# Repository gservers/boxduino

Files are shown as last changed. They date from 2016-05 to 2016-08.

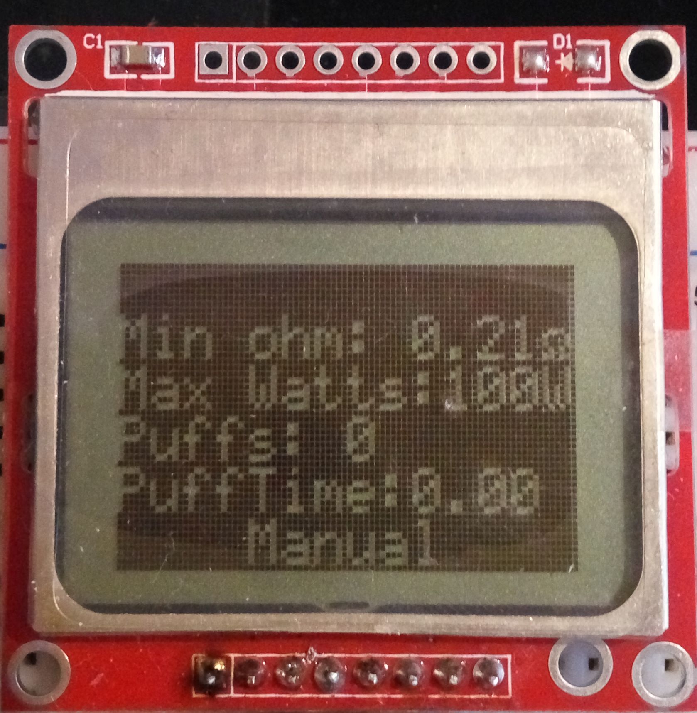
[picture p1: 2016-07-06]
Gallery/6.1.ManualStatistics+inverted.jpg

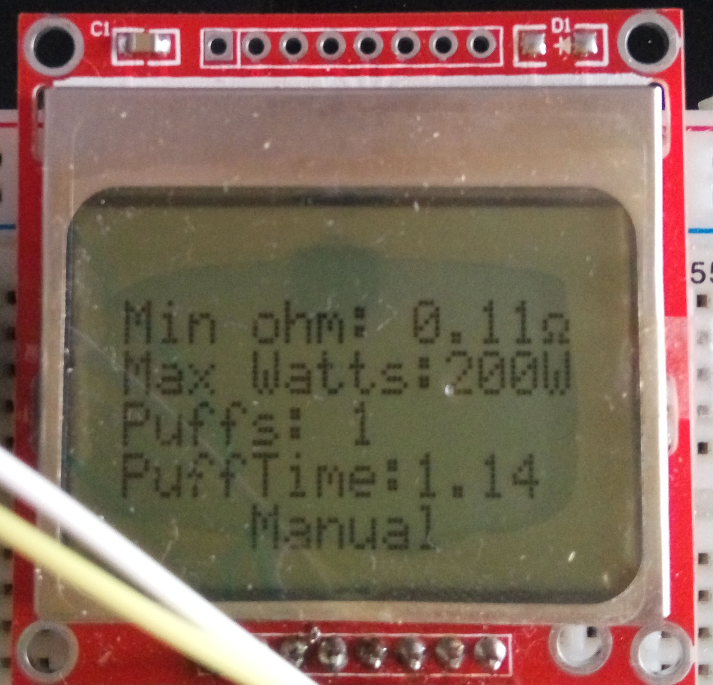
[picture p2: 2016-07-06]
Gallery/6.1.ManualStatistics.jpg

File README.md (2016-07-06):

# BOXduino - the first Arduino powered e-cigarette!  

Let me introduce You to one of the first almost open source Arduino BOX MOD - BOXduino!  
It took much work, and I'm still not finished! Time to solder this up, because breadboard tests are promising.

###Currently working:
  * Ohmmeter!  
  * Sleep / Power on - makes BOXduino more powersaving!  
  * Firing - It's self-explainatory! 
  * Read input voltage - Watch battery level!  
  * Battery indicator (pretty accurate) - with awesome bettery graphics!  
  * Nice display! - Pretty fine and readable layout  
  * Screen dimming! - afer 10 seconds without any action the screen will be dimmed.  
  * Standard control - see controls below  
  * Screen refreshing! - RMS voltage and resistance, the only thing that should be  
  * 1:1 Scheme - just solder it up! The only changes will be in code! (i hope)
  * Statistics submenu - check how low You can get, check puffs and mode

###Controls:  
  * Refresh everything: 1x click  
  * Fire: Hold the button  
  * Switch VV / Bypass: 3x click  
  * Night mode (inverting display): 4x click 
  * Power off: 5x click  
  * Power on: Hold the button (while off)  
  * Serial debug: 6x click  
  * Wakeup the screen: 1x click  
  * Change resistance (potentiometer on 0 and manual = true): 2x click
  * Check puffs, minimal resistance and max wattage: 2x click
  
###Ohmmeter
LM317 is taking over 125mA all the time, which makes me cry. Why would I waste my batteries for such thing?  
So i decided to use S8050 bipolar NPN transistor (up to 0.5A!) to supply power.
Now LM317 is powered just when I need to.

There are two modes available - manual and automatic.  
To change them edit bool called "manual".  

(false) Automatic is pretty easy to explain - ohmmeter circuit (and code) is calculating resistance almost all the time.    
(true) Manual - if You can't/don't want to add LM317 circuit, the resistance is set by yourself.  

You must know the resistance of the coil, but before I add TC it's just to show watts.  
Device will automatically ask for resistance, just turn potentiometer to desired value and press fire.  
To change, just press fire two times with potentiometer on 0.  

I didn't get any feedback, but if You find something hard to understand just pm me.  
##Check Issues for ToDo list and feel free to add new suggestions!

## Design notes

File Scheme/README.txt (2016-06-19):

1. Import PCD8544LCD.fzpz to Fritzing
2. Open BOXduino.fzz

My PCD8544 pinout:
Pin 1 - VCC
Pin 2 - GND
Pin 3 - SCE
Pin 4 - RST
Pin 5 - D/C
Pin 6 - DN(MOSI)
Pin 7 - SCLK
Pin 8 - Backlight
Please make sure Your pinout is the same or make needed fixes in Your circuit.
PCD8544.h will also need to be modified.

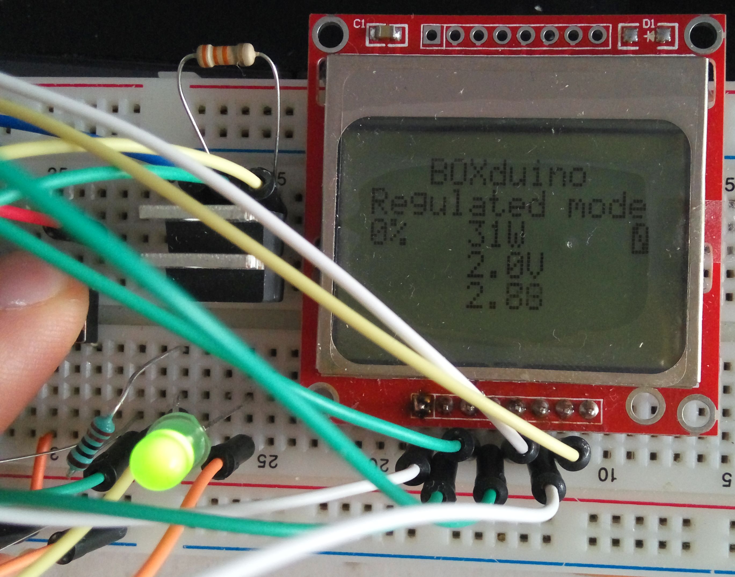
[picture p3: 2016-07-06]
Gallery/4.Firing.jpg

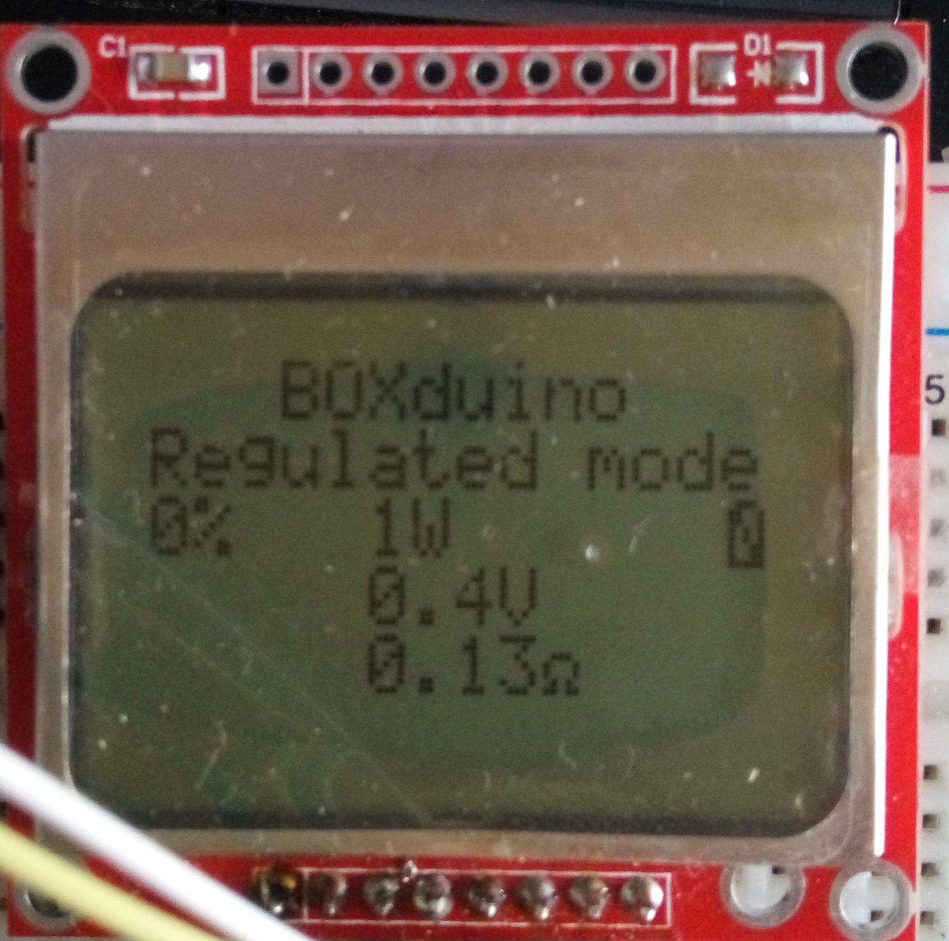
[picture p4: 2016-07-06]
Gallery/3.MainScreen.jpg

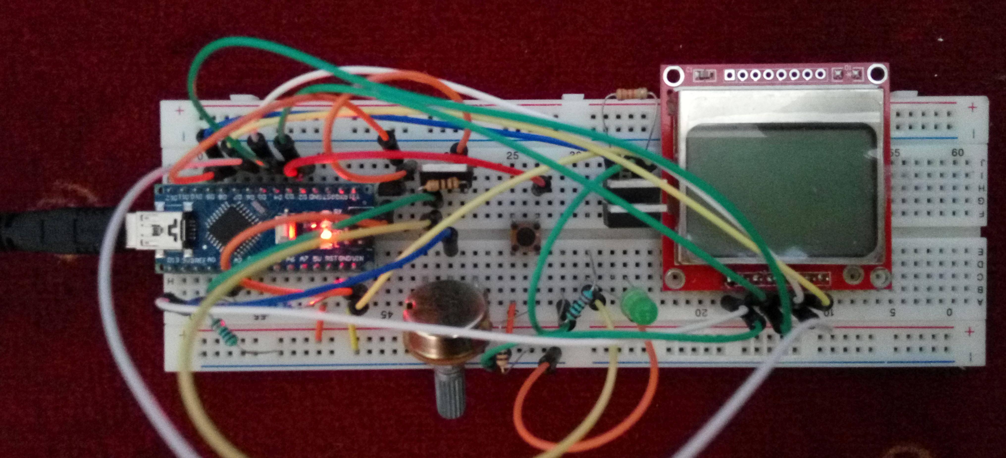
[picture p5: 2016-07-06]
Gallery/7.1.Breadboard.jpg

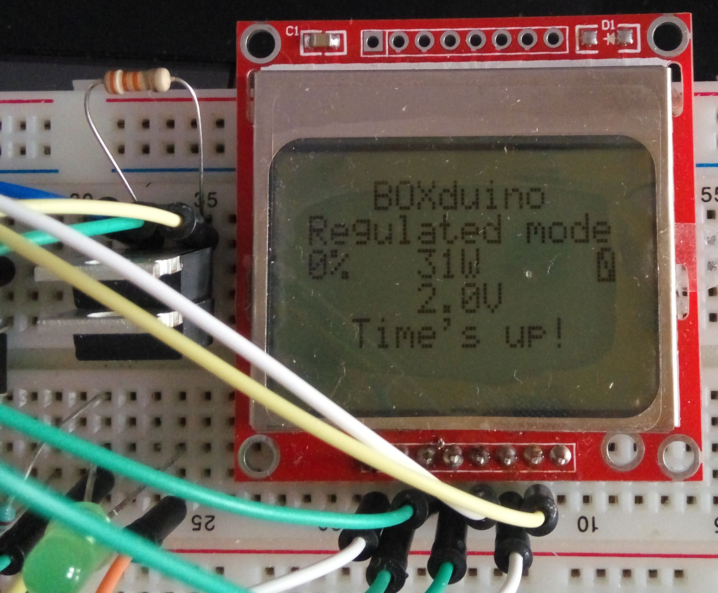
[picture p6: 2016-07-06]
Gallery/5.Timeout.jpg

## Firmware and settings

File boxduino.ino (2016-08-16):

/*  Arduino controlled box mod by Marek Ledworowski.
    I'm not responsible for dead MCU's, burnt PC's,
    smoked cigarettes or electrocutions.
    I'm not responsible for this sketch, even if it
    poops on your lawn - You let him do it.

    Please don't sell it as Yours, but feel free to use
    it WITHOUT financial benefits.
    Any questions? Contact me at fotelpl@gmail.com

    To do:
      - lock for too low/high resistance
      - lock for too high power
*/

#include "libraries/PCD8544/PCD8544.h" //LCD Library
#include "libraries/ClickButton/ClickButton.h" //Fire button driver
#include <avr/sleep.h> //Sleeping lib
#include <avr/power.h> //^up
static PCD8544 lcd;
bool manual = true; //true for LM317 circiut, false for manual setting
bool on = true; //Check if powered
bool inv = false; //Screen inverted
bool lock = false; //Autofire
const int baud = 9600; //Serial baudrate
const int maxwatt = 100; //Max watts

ClickButton fire(2, HIGH); //Define fire button as object
const int pfet = 9; //Trigger (+) channel of P-FET
const int ohmmetpower = 8; //Ohmmeter power supply
const int pot = A0; //Potentiometer
const int volt = A1; // Vin voltmeter
const int ohmmet = A2; //Ohmmeter output

const int probes = 15; //How many resistance samples will be taken
const float r1 = 1000000.0; //R1 of Vin voltmeter
const float r2 = 100000.0; //R2 Vin voltmeter
const float vin = 8.4; //Max. supply voltage
const float vbord = 6; //Max. discharge voltage
const float ohmcal = 0.08; //Resistance of connections, just put copper wire between pins.
//Check the readings and change value if needed

int mode = 0; //0 - VV/VW, 1 - BYPASS
int cnt = 0; //How many times button was pressed
long int tempnow; //First click
long int tempend; //Last click
long int lastpress = 0; //Last button press
unsigned int puffs = 0; //Total puffs
float pufftime = 0; //Total puff time

float state = 0; //% of potentiometer scale
float rms = 0;  //RMS voltage
float duty = 0; //duty cycle (0-255)
float vbat = 0; //Vin voltage
float cbat = 0; //Baterry %
float res = 0; //Resistance
float minres = 0; //Minimal resistance
int watts = 0; //Watts

const int timeout = 10; //Fire limit
const int dim = 10; //Disable display limit

const unsigned char full[] = {
  0xFE, 0xFF, 0xFF, 0xFF, 0xFE
};
const unsigned char hi[] = {
  0xFE, 0xFD, 0xFD, 0xFD, 0xFE
};
const unsigned char med[] = {
  0xFE, 0xF1, 0xF1, 0xF1, 0xFE
};
const unsigned char low[] = {
  0xFE, 0xC1, 0xC1, 0xC1, 0xFE
};
const unsigned char empty[] = {
  0xFE, 0x87, 0x99, 0xE1, 0xFE
};
const unsigned char ohm[] = {
  0x58, 0x64, 0x04, 0x64, 0x58
};
const unsigned char splashscreen[] = {
  0x00, 0x00, 0x00, 0xFE, 0x0C, 0x30, 0x60, 0x30, 0x0C, 0xFE, 0x00, 0x80, 0x40, 0x40, 0x40, 0xC0, 0x00, 0x00, 0xC0, 0x80, 0x40, 0x40, 0x00, 0x80, 0x40, 0x40, 0x40, 0x80, 0x00, 0x80, 0x40, 0x40, 0x40, 0x00, 0xFE, 0x00, 0x00, 0x00, 0x00, 0x00, 0x08, 0x04, 0x02, 0x80, 0x40, 0x20, 0x40, 0x80, 0x00, 0x00, 0x00, 0x00, 0x00, 0x00, 0x00, 0x00, 0x00, 0x00, 0x00, 0x00, 0x00, 0x00, 0x00, 0xC0, 0x40, 0x78, 0x7C, 0x78, 0x40, 0xC0, 0x00, 0x00, 0x00, 0x00, 0x00, 0x00, 0x00, 0x00, 0x00, 0x00, 0x00, 0x00, 0x00, 0x00,
  0x00, 0x00, 0x00, 0x07, 0x00, 0x00, 0x00, 0x00, 0x00, 0x07, 0x00, 0x03, 0xF4, 0x14, 0x14, 0x13, 0xE4, 0x00, 0x07, 0x00, 0x00, 0x00, 0x00, 0x03, 0x05, 0x05, 0x05, 0x00, 0x00, 0x03, 0x04, 0x04, 0x04, 0x00, 0x03, 0xF4, 0x04, 0x04, 0x02, 0x00, 0x00, 0x00, 0x00, 0x04, 0x84, 0x04, 0x02, 0x01, 0x00, 0x00, 0x00, 0x00, 0x00, 0x00, 0x00, 0x00, 0x00, 0x00, 0x00, 0x00, 0x00, 0x00, 0x03, 0xFF, 0x00, 0x0F, 0x05, 0x0F, 0x00, 0xFF, 0x00, 0x00, 0x00, 0x00, 0x00, 0x00, 0x00, 0x00, 0x00, 0x00, 0x00, 0x00, 0x00, 0x00,
  0x00, 0x00, 0x00, 0x00, 0x00, 0x00, 0x00, 0x00, 0x00, 0x00, 0x00, 0x00, 0x3F, 0x21, 0x21, 0x21, 0x22, 0x1C, 0x00, 0x1C, 0x22, 0x22, 0x22, 0x1C, 0x00, 0x22, 0x14, 0x08, 0x14, 0x22, 0x00, 0x1C, 0x22, 0x22, 0x22, 0x3F, 0x00, 0x1E, 0x20, 0x20, 0x20, 0x1E, 0x20, 0x00, 0x3E, 0x00, 0x3E, 0x04, 0x02, 0x02, 0x3C, 0x00, 0x1C, 0x22, 0x22, 0x22, 0x1C, 0x00, 0x00, 0x00, 0x00, 0x00, 0x00, 0x03, 0x02, 0x02, 0x02, 0x02, 0x02, 0x03, 0x00, 0x00, 0x00, 0x00, 0x00, 0x00, 0x00, 0x00, 0x00, 0x00, 0x00, 0x00, 0x00, 0x00,
  0x00, 0x00, 0x00, 0x00, 0x00, 0x00, 0x00, 0x00, 0x00, 0x00, 0x00, 0x00, 0x00, 0x00, 0x00, 0x00, 0x00, 0x00, 0x00, 0x00, 0x00, 0x00, 0x00, 0x00, 0x00, 0x00, 0x00, 0x00, 0x00, 0x00, 0x00, 0x00, 0x00, 0x00, 0x00, 0x00, 0x00, 0x00, 0x00, 0x00, 0x00, 0x00, 0x00, 0x00, 0x00, 0x00, 0x00, 0x00, 0x00, 0x00, 0x00, 0x00, 0x00, 0x00, 0x00, 0x00, 0x00, 0x00, 0x00, 0x00, 0x00, 0x00, 0x00, 0x00, 0x00, 0x00, 0x00, 0x00, 0x00, 0x00, 0x00, 0x00, 0x00, 0x00, 0x00, 0x00, 0x00, 0x00, 0x00, 0x00, 0x00, 0x00, 0x00, 0x00,
  0x00, 0x00, 0x00, 0x00, 0x00, 0x00, 0x00, 0x00, 0x00, 0x00, 0x00, 0x00, 0x00, 0x00, 0x00, 0x00, 0x00, 0x00, 0x00, 0x00, 0x00, 0x00, 0x00, 0x00, 0x00, 0x00, 0x00, 0x00, 0x00, 0x00, 0x00, 0x00, 0x00, 0x00, 0x00, 0x00, 0x00, 0x00, 0x00, 0x00, 0x00, 0x00, 0x00, 0x00, 0x00, 0x00, 0x00, 0x00, 0x00, 0x00, 0x00, 0x00, 0x00, 0x00, 0x00, 0x00, 0x00, 0x00, 0x00, 0x00, 0x00, 0x00, 0x00, 0x00, 0x00, 0x00, 0x00, 0x00, 0x00, 0x00, 0x00, 0x00, 0x00, 0x00, 0x00, 0x00, 0x00, 0x00, 0x00, 0x00, 0x00, 0x00, 0x00, 0x00,
  0x00, 0x00, 0x00, 0x00, 0x00, 0x00, 0x00, 0x00, 0x00, 0x00, 0x00, 0x00, 0x00, 0x00, 0x00, 0x00, 0x00, 0x00, 0x00, 0x00, 0x00, 0x00, 0x00, 0x00, 0x00, 0x00, 0x00, 0x00, 0x00, 0x00, 0x00, 0x00, 0x00, 0x00, 0x00, 0x00, 0x00, 0x00, 0x00, 0x00, 0x00, 0x00, 0x00, 0x00, 0x00, 0x00, 0x00, 0x00, 0x00, 0x00, 0x00, 0x00, 0x00, 0x00, 0x00, 0x00, 0x00, 0x00, 0x00, 0x00, 0x00, 0x00, 0x00, 0x00, 0x00, 0x00, 0x00, 0x00, 0x00, 0x00, 0x00, 0x00, 0x00, 0x00, 0x00, 0x00, 0x00, 0x00, 0x00, 0x00, 0x00, 0x00, 0x00, 0x00
};
void setup() {
  lcd.begin();
  lcd.setContrast(65); //We want to see something, right?
  lcd.drawBitmap(splashscreen, 84, 48);
  setPwmFrequency(9, 1); //31372.55Hz, 256 cycle length (0-255)
  pinMode(pot, INPUT); //Potentiometer
  pinMode(volt, INPUT); //Voltmeter
  pinMode(2, INPUT); //Button
  pinMode(pfet, OUTPUT); //P-FET transistor out
  pinMode(ohmmetpower, OUTPUT); //Ohmmeter power supply
  pinMode(ohmmet, INPUT); //Ohmmeter
  prepchar(); //Send custom chars to display's RAM
  fire.debounceTime = 10; //Single click
  fire.multiclickTime = 400; //Time for many clicks
  fire.longClickTime = 200; //Long click timer
  on = true; //Set this flag to enable screen and stuff
  digitalWrite(pfet, HIGH); //Make sure it won't fire without us
  digitalWrite(ohmmetpower, LOW); //Disable ohmmeter
  vbat = gainvbat(volt, r1, r2); //Performing initial calculations
  minres = vbat * vbat / maxwatt;
  switch (mode) {
    case 0: //VV/VW
      duty = gainduty(pot); rms = gainrms(vbat, duty);
      watts = round(rms * rms / res); break;
    case 1: //Bypass
      duty = 255; rms = vbat; break;
  } //As far, we're finished
  delay(1500);
  lcd.clear();
  if (manual == false)
    res = gainres(ohmmetpower, ohmmet, probes); //LM317 is present so it checks resistance
  else res = setohm(pot); //No LM317 = no automatic updates
  lcd.setCursor(0, 0);
  printstate(vbat, duty, rms, mode, res);
  lastpress = millis();
}

void loop() {
  fire.Update();
  vbat = gainvbat(volt, r1, r2);
  switch (mode) {
    case 0:
      duty = gainduty(pot); rms = gainrms(vbat, duty);
      watts = round(rms * rms / res); break;
    case 1:
      duty = 255; rms = vbat;
      watts = round(rms * rms / res); break;
  }

  lcd.setCursor(30, 2);
  lcd.print(watts);
  lcd.print("W  ");
  lcd.setCursor(30, 3);
  lcd.print(rms, 1);
  lcd.print("V");
  lcd.setCursor(30, 4);
  if (res > 9.99) res = 9.99;
  if (res < 0.03) res = 0.00;
  lcd.print(res, 2);
  lcd.write(0);

  duty = abs(duty - 255); //P-FET transistor reacts to low state soooo...
  //The value must be inverted
  fire.Update();
  cnt = fire.clicks;
  if (cnt != 0) lastpress = millis();
  switch (cnt) {
    case -1:
      if (digitalRead(2) == 1 && lock == false && res > minres) {
        printstate(vbat, duty, rms, mode, res);
        go(pfet, duty, 2);
        printstate(vbat, duty, rms, mode, res);
      }
      if (digitalRead(2) == 1 && lock == false && res < minres) {
        lcd.setCursor(0, 3);
        lcd.print(" Too low ohm!");
        while (digitalRead(2) == HIGH) {}
        lcd.clearLine();
      }
      break;
    case 1:
      if (lock == true) {
        lcd.begin();
        lcd.setContrast(65);
      }
      else if (manual == false) res = gainres(ohmmetpower, ohmmet, probes);
      lock = false;
      prepchar();
      printstate(vbat, duty, rms, mode, res); break;
    case 2:
      lcd.clear();
      if (/*manual == true && */analogRead(pot) <= 5) res = setohm(pot);
      else {
        lcd.setCursor(0, 0);
        lcd.print("Min ohm: ");
        lcd.print(minres);
        lcd.write(0);
        lcd.setCursor(0, 1);
        lcd.print("Max Watts:");
        lcd.print(maxwatt);
        lcd.print("W");
        lcd.setCursor(0, 2);
        lcd.print("Puffs: ");
        lcd.print(puffs);
        lcd.setCursor(0, 3);
        lcd.print("PuffTime:");
        lcd.print(pufftime, 2);
        lcd.setCursor(0, 5);
        if (manual == true)lcd.print("    Manual");
        else lcd.print("  Automatic");
        delay(2000);
      }
      lcd.clear();
      printstate(vbat, duty, rms, mode, res); break;
    case 3:
      if (mode == 1) {
        mode = 0;
        duty = gainduty(pot);
        rms = gainrms(vbat, duty);
        watts = round(rms * rms / res);
      } else {
        mode = 1;
        duty = 255;
        rms = vbat;
      }
      printstate(vbat, duty, rms, mode, res); break;
    case 4:
      if (inv == 1) inv = 0; else inv = 1;
      lcd.setInverse(inv); break;
    case 5:
      on = false; power();
      printstate(vbat, duty, rms, mode, res); break;
    case 6:
      serv(baud, vbat, duty, rms, mode, puffs, pufftime, res); break;
  }
  if (cnt != 0) lastpress = millis();
  if ((millis() - lastpress) >= (dim * 1000) && cnt == 0 && lock == false) {
    lcd.stop();
    lock = true;
  }
}
//MOSFET port, duty cycle, fire button port
void go(int pftmp, float dutmp, int fitmp) {
  float czas = millis();
  float licz = 0;
  lcd.setCursor(0, 4);
  lcd.clearLine();
  analogWrite(pfet, dutmp);
  while (digitalRead(fitmp) != 0 && licz <= timeout) { //It's not rocket science
    licz = (millis() - czas) / 1000;
    lcd.setCursor(30, 4);
    lcd.print(licz, 2);
  }
  digitalWrite(pfet, HIGH);
  delay(5);
  if (licz >= timeout) {
    lcd.setCursor(33, 4);
    delay(45);
    lcd.print("10.00");
    lcd.clearLine();
    lcd.print("  Time's up!  ");
    while (digitalRead(fitmp) == 1) {}
    delay(2500);
    lcd.clearLine();
    licz = timeout;
  }
  pufftime += licz;
  lcd.setCursor(0, 4);
  lcd.clearLine();
  puffs = puffs + 1;
}
//Potentiometer port
int gainduty(float potmp) {
  float dutmp = analogRead(potmp);
  Serial.print(duty);
  Serial.print(" | ");
  dutmp = map(dutmp, 0, 1023, 0, 255);
  Serial.println(duty);
  return (dutmp);
}
//Vin voltmeter port, R1, R2
float gainvbat(int batmp, float rtmp1, float rtmp2) {
  float vbatmp = ((analogRead(batmp) * 5.0) / 1024.0) / (rtmp2 / (rtmp1 + rtmp2));
  return (vbatmp);
}
//Vin voltage, duty cycle
float gainrms(float vbatmp, float dutmp) {
  float statmp = (dutmp * 100) / 255; //Stan w %
  float rmstmp = vbatmp * sqrt(statmp / 100); //RMS
  return (rmstmp);
}
float setohm(int potmp) { //If you know resistance of coil
  float tempohm;
  lcd.setCursor(0, 0);
  lcd.print("Set Resistance");
  lcd.setCursor(0, 2);
  lcd.print("Min ohm: ");
  lcd.print(minres);
  lcd.write(0);
  lcd.setCursor(0, 3);
  lcd.print("Max Watts:");
  lcd.print(maxwatt);
  lcd.print("W");
  lcd.setCursor(0, 4);
  lcd.print("Puffs: ");
  lcd.println(puffs);
  lcd.setCursor(0, 5);
  lcd.print("PuffTime:");
  lcd.println(pufftime, 1);
  while (digitalRead(2) != true) {
    lcd.setCursor(0, 0);
    lcd.print("Set Resistance");
    tempohm = analogRead(potmp);
    tempohm /= 1023.0; //9.99 ohm max
    tempohm *= 999;
    tempohm = ceil(tempohm);
    tempohm /= 100;
    lcd.setCursor(30, 1);
    lcd.print(tempohm);
    lcd.write(0);
  }
  lcd.clear();
  return (tempohm);
}
//Ohmmeter power supply pin, ohmmeter reading pin, how many probes
//Remember to DISABLE P-FET transistor and/or N-FET!
float gainres(int ohmsuptmp, int ohmmetmp, int probetmp) {
  float tempres = 0;
  float tp = 0;
  digitalWrite(ohmsuptmp, HIGH);
  delayMicroseconds(10);
  for (int a = 0; a < probes; a++) {
    tp = analogRead(ohmmetmp);
    tp = tp * 5 / 1023;
    tp = tp / 0.125;
    tempres += tp;
  }
  digitalWrite(ohmsuptmp, LOW);
  tempres /= probetmp;
  tempres -= ohmcal;
  return (tempres);
}
//Shutdown
void power() {
  digitalWrite(pfet, HIGH);
  do {
    attachInterrupt(2, poweron, HIGH);
    lcd.stop();
    set_sleep_mode(SLEEP_MODE_IDLE);
    sleep_enable();
    sleep_mode();
    sleep_disable();
    long int teemp = millis();
    while (digitalRead(2) == HIGH) {
      if ((millis() - teemp) >= 2500) on = true;
    }
    detachInterrupt(2);
    if (on == true) lcd.setPower(true); //Do something here to show it's working again
  } while (on == false);
}
void poweron() {
  detachInterrupt(2);
}
void prepchar() {
  lcd.createChar(0, ohm);
  lcd.createChar(1, full);
  lcd.createChar(2, hi);
  lcd.createChar(3, med);
  lcd.createChar(4, low);
  lcd.createChar(5, empty);
}
void serv(int tmpbaud, float vbatmp, float dutmp, float rmstmp, int modtmp, int pufftmp, float pufftmp2, float restmp) {
  Serial.begin(tmpbaud);
  Serial.println("BOXduino service mode");
  Serial.print("Supply voltage: ");
  Serial.print(vbatmp, 1);
  Serial.print("V\n");
  Serial.print("Mode: ");
  if (mode == 0) Serial.print("Regulated\n");
  if (mode == 1) Serial.print("Bypass\n");
  Serial.print("RMS voltage: ");
  Serial.print(rmstmp, 1);
  Serial.print("V\n");
  Serial.print("Digital duty cycle: ");
  Serial.print(dutmp, 0);
  Serial.print("/255\n");
  Serial.print("Puffs: ");
  Serial.println(pufftmp);
  Serial.print("Puff time: ");
  Serial.print(pufftmp2, 2);
  Serial.println("s");
  Serial.print("Resistance: ");
  Serial.print(restmp);
  Serial.println("ohm");
  Serial.println("-=-=-=-=-=-=-=-=-=-=-=-=-=-=-");
  Serial.end();
}
void printstate(float vbatmp, float dutmp, float rmstmp, int modtmp, float restmp) {
  cbat = ((vbatmp - vbord) * 100);
  if (cbat < 0) cbat = 0;
  lcd.setCursor(0, 0);
  lcd.print("   BOXduino");
  lcd.setCursor(0, 1);
  if (modtmp == 0) lcd.print("Regulated mode");
  if (modtmp == 1) lcd.print(" Bypass mode! ");
  lcd.setCursor(0, 2);
  lcd.print(cbat, 0);
  lcd.print("% ");
  lcd.setCursor(30, 2);
  int watts = round(rms * rms / res);
  lcd.print(watts);
  lcd.print("W   ");
  lcd.setCursor(79, 2);
  if (cbat <= 100 && cbat >= 95) lcd.write(1);
  if (cbat < 95 && cbat >= 70) lcd.write(2);
  if (cbat < 70 && cbat >= 40) lcd.write(3);
  if (cbat < 40 && cbat >= 15) lcd.write(4);
  if (cbat < 15) lcd.write(5);
  lcd.setCursor(30, 3);
  lcd.print(rmstmp, 1);
  lcd.print("V");
  lcd.setCursor(30, 4);
  if (restmp > 9.99) restmp = 9.99;
  if (restmp < 0.03) restmp = 0.00;
  lcd.print(restmp, 2);
  lcd.write(0);
}
void setPwmFrequency(int pin, int divisor) {
  byte mode;
  if (pin == 5 || pin == 6 || pin == 9 || pin == 10) {
    switch (divisor) {
      case 1: mode = 0x01; break;
      case 8: mode = 0x02; break;
      case 64: mode = 0x03; break;
      case 256: mode = 0x04; break;
      case 1024: mode = 0x05; break;
      default: return;
    }
    if (pin == 5 || pin == 6) {
      TCCR0B = TCCR0B & 0b11111000 | mode;
    } else {
      TCCR1B = TCCR1B & 0b11111000 | mode;
    }
  } else if (pin == 3 || pin == 11) {
    switch (divisor) {
      case 1: mode = 0x01; break;
      case 8: mode = 0x02; break;
      case 32: mode = 0x03; break;
      case 64: mode = 0x04; break;
      case 128: mode = 0x05; break;
      case 256: mode = 0x06; break;
      case 1024: mode = 0x7; break;
      default: return;
    }
    TCCR2B = TCCR2B & 0b11111000 | mode;
  }
}

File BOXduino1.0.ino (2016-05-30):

/*  Arduino controlled box mod by Marek Ledworowski
    Before committing changes please contact me first
    at fotelpl@gmail.com .
    I'm not responsible for dead MCU's, burnt lungs
    and all stuff that may be dangerous or sad.
    Version 1.0
*/
    
#include <avr/sleep.h>
#include <avr/power.h>
#include <LiquidCrystal.h>
LiquidCrystal lcd(7, 8, 9, 10, 11, 12);
bool on = true; //Stan wlaczenia
const int fire = 2; //Przycisk
const int mosfet = 6; //Wyjscie (PWM)
const int pot = A0; //Potencjometr
const int volt = A1; //Woltomierz Vin
const int bcg = A2; //Podswietlenie ekranu

int mode = 0; //0 - VV/VW, 1 - BYPASS
int bouncedelay = 100;
int holddelay = 500;

long int tempnow; //Poczatek klikania
long int tempend; //Koniec klikania

const float r1 = 1000000.0; //R1 woltomierza Vin
const float r2 = 100000.0; //R2 woltomierza Vin

float state = 0; //Wychylenie w %
float rms = 0;  //Napięcie RMS
float duty = 0; //Dlugosc cyklu 0-255
float vbat = 0; //Napiecie zasilania
float vin = 8.4; //Napiecie referencyjne zasilania
float vbord = 6; //Granic rozladowania
float cbat = 0; //% naladowania baterii
float ohm = 0; //omomierz
float light = 256.0; //Jasnosc podswietlenia
byte full[8] = {
  B00000,
  B01110,
  B11111,
  B11111,
  B11111,
  B11111,
  B11111,
  B00000,
};
byte hi[8] = {
  B00000,
  B01110,
  B10001,
  B11111,
  B11111,
  B11111,
  B11111,
  B00000,
};
byte med[8] = {
  B00000,
  B01110,
  B10001,
  B10001,
  B11111,
  B11111,
  B11111,
  B00000,
};
byte low[8] = {
  B00000,
  B01110,
  B10001,
  B10001,
  B10001,
  B11111,
  B11111,
  B00000,
};
byte empty[8] = {
  B00000,
  B01110,
  B11001,
  B10101,
  B10101,
  B10011,
  B11111,
  B00000,
};
void setup() {
  pinMode(pot, INPUT);
  pinMode(volt, INPUT);
  pinMode(bcg, OUTPUT);
  pinMode(fire, INPUT);
  pinMode(mosfet, OUTPUT);
  lcd.begin(16, 2);
  lcd.createChar(0, full);
  lcd.createChar(1, hi);
  lcd.createChar(2, med);
  lcd.createChar(3, low);
  lcd.createChar(4, empty);
  analogWrite(bcg, light);
  vbat = gainvbat(volt, r1, r2);
  duty = gainduty(pot);
  rms = gainrms(vbat, duty);
  scheme(mode);
  updatebat(vbat);
}
void loop() {
  vbat = gainvbat(volt, r1, r2);
  duty = gainduty(pot);
  rms = gainrms(vbat, duty);
  scheme(mode);
  updatedata(rms, mode);
  if (millis() % 2000 == 0) updatebat(vbat);

  if (rms < 0.1 && digitalRead(fire) == HIGH ) {
    tempnow = millis();
    while (digitalRead(fire) == HIGH) {}
    tempend = millis();
    if ((tempend - tempnow) >= holddelay) {
      on = false;
      power();
    } else if ((tempend - tempnow) < bouncedelay) {
      if (mode == 1) mode = 0;
      else mode = 1;
      lcd.clear();
    }
  } else if (digitalRead(fire) == HIGH && rms >= 0.1) {
    tempnow = millis();
    while (millis() - tempnow < bouncedelay && digitalRead(fire) == HIGH) {}
    if (mode == 0 && digitalRead(fire) == HIGH) watt(mosfet, duty, fire);
    if (mode == 1 && digitalRead(fire) == HIGH) bypass(mosfet, fire);
    updatebat(vbat);
  }
  delay(10);
}

void scheme(int motmp) {
  lcd.setCursor(0, 0);
  if (mode == 0)
    lcd.print(" VAPE AT: ");
  if (mode == 1)
    lcd.print("BYPASS AT: ");
}

void updatebat(float tmpvbat) {
  float cbat = ((tmpvbat - vbord) * 100) / vin;
  if (cbat < 0) cbat = 0;
  if (cbat == 100) lcd.setCursor(10, 1);
  if (cbat < 100 && cbat >= 10) lcd.setCursor(11, 1);
  if (cbat < 10) lcd.setCursor(12, 1);
  lcd.print(cbat, 0);
  lcd.print("% ");
  if (cbat <= 100 && cbat >= 95) lcd.write(byte(0));
  if (cbat < 95 && cbat >= 70) lcd.write(byte(1));
  if (cbat < 70 && cbat >= 40) lcd.write(byte(2));
  if (cbat < 40 && cbat >= 15) lcd.write(byte(3));
  if (cbat < 15) lcd.write(byte(4));
  lcd.setCursor(0, 0);
}

void updatedata(float rmstmp, float motmp) {
  if (motmp == 0) {
    lcd.setCursor(10, 0);
    lcd.print(rms, 1);
    lcd.print("V");
  }
}

void watt(int mostmp, float dutmp, int fitmp) { //mosfet, duty, fire
  float czas = millis();
  float licz = 0;
  analogWrite(mostmp, dutmp);
  while (digitalRead(fitmp) != 0 && licz < 10)
    licz = (millis() - czas) / 1000;
  analogWrite(mostmp, 0.0);
  if (licz >= 10) {
    while (digitalRead(fitmp) == 1) {}
    delay(2500);
  }
}

void bypass(int mostmp, int fitmp) { //mosfet, fire
  float czas = millis();
  float licz = 0;
  analogWrite(mostmp, 255);
  while (digitalRead(fitmp) != 0 && licz < 10)
    licz = (millis() - czas) / 1000;
  analogWrite(mostmp, 0.0);
  if (licz >= 10) {
    while (digitalRead(fitmp) == 1) {};
    delay(2500);
  }
}

float gainvbat(int batmp, float rtmp1, float rtmp2) {
  float value = analogRead(batmp);
  float vout = (value * 5.0) / 1024.0;
  float vbatmp = vout / (rtmp2 / (rtmp1 + rtmp2));
  return (vbatmp);
}

int gainduty(float potmp) {
  float dutmp = analogRead(potmp);
  dutmp /= 4;
  dutmp = round(dutmp);
  return (dutmp);
}

float gainrms(float vbatmp, float dutmp) {
  float statmp = (dutmp * 100) / 255; //Stan w %
  float rmstmp = vbatmp * sqrt(statmp / 100); //RMS
  return (rmstmp);
}

void power() {
  attachInterrupt(fire, poweron, HIGH);
  lcd.clear();
  analogWrite(bcg, 0.0);
  lcd.noDisplay();
  set_sleep_mode(SLEEP_MODE_IDLE);
  sleep_enable();
  sleep_mode();
  while (on == false && digitalRead(fire) == LOW) {}
  if (on == false) poweron();
  sleep_disable();
  lcd.display();
  analogWrite(bcg, light);
}

void poweron() {
  detachInterrupt(fire);
  long int teemp = millis();
  while (digitalRead(fire) == HIGH) {}
  if ((millis() - teemp) >= 2000) on = true;
  power();
}

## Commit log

2016-05-31 Renaming file
    Making ground to use PCD8544 library.
    Preparing to add LM317T based ohmmeter.
2016-06-01 Added scheme
    Removed almost everything about old display.
    Preparing t use PCD8544
    Added ohmmeter
    [boxduino.fzz]
2016-06-03 Little fixes
    Added ClickButton library to manage button
2016-06-05 Little changes in wiring
    [boxduino.fzz]
2016-06-05 Added display
    + awesome battery icons!
2016-06-07 Fixes
    Added external libraries, simple screen and something more
    [boxduino.fzz]
2016-06-08 Added splash
    Known bugs:
    * Puff counter adds two puffs instead of one
    * Mode changing dosen't work properly
    * Due to broken Arduino I can't say if other things work fine
2016-06-09 Update
    * Shorted formules
    * Made firing function universal
    * A bit adjusted button settings
    * Showing atty voltage
    Photos coming soon!
2016-06-12 Removed ohmmeter
    I discovered the battery + and ohmmeter - would be ALWAYS connected through the coil.
    This would cause permanent firing.
    Oh, and now I'm trying to add 5click unlock :))
2016-06-12 Screensaving added
    10 after last button press the screen will be disabled.
    Enabling by pressing button once
2016-06-15 Little changes in wiring
    Please use this instead of fritzing scheme (temporarily of course).
    Using 1xLM317 with 10ohm resistor (connectrd through SS8050 bipolar transistor) and 2xIRF9540 (P channel FET transistor)
2016-06-16 Small additions
    Added legal notices
    Added library descriptions
    Still need to prepare them for changing PWM mode (every delay() and millis() need to be multiplied by 64!)
2016-06-18 trying to fix delays and millis()
2016-06-19 small bugs discovered
    [boxduino.fzz]
2016-06-19 added power limit
2016-06-19 screwed one function. need a cleanup. dammit.
2016-07-06 i don't even know what's fixed...
    [boxduino.ino]
